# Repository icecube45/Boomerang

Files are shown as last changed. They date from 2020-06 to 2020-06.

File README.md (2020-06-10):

# Boomerang

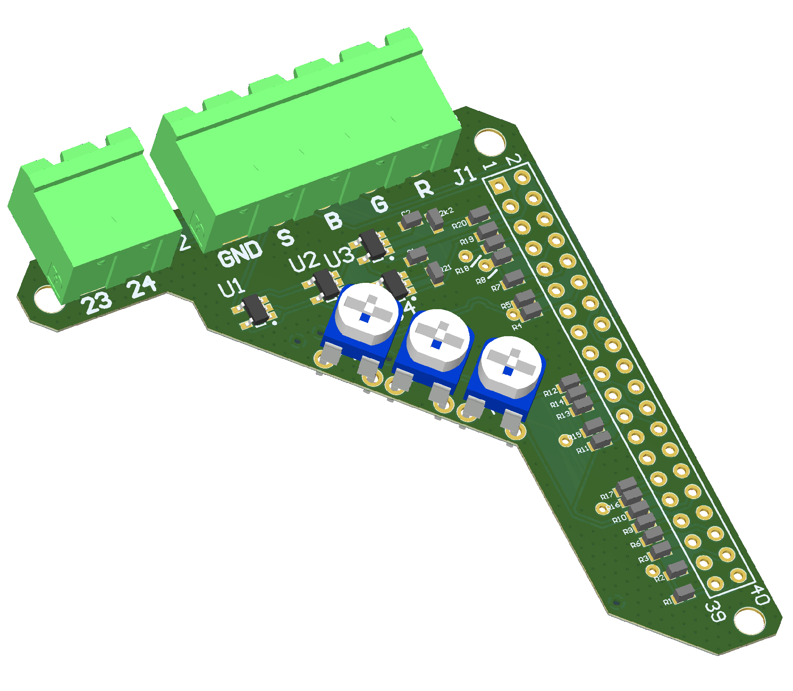
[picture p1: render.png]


## Purpose

Boomerang plugs directly into the 40 pin header of a Raspberry Pi and allows for RGBS output, rather than the usual HDMI. This board integrates a Gert VGA 666, and composite sync combiner.

Boomerang also exposes GPIO 23 and GPIO 24 to an external connector, which I'm using to communicate with a [Mausberry Car Supply](https://mausberry-circuits.myshopify.com/).

Three trimpots are installed to allow for slight color correction of the R G and B signals.

Combined with the [Screen Slaver](https://github.com/icecube45/G37ScreenSlaver), Boomerang allows for easy car computer integration into an Infiniti G37.

## Software config
The following must be added to your raspberry pi's config.txt in order to output RGBS video
```
dtoverlay=vga666
enable_dpi_lcd=1
display_default_lcd=1
dpi_group=2
dpi_mode=87
hdmi_timings=480 1 31 35 64 234 1 12 10 10 0 0 0 60 0 9600000 1
```

## Gotchas

* The effective resolution with the Boomerang and supplied config is 480x234. Not great, but actually looks ok on the Infiniti G37 display. If you find a config that allows for a 'higher' resolution, please submit a pull request!

#### Changelog:

* 6/9/2020: Initial Release

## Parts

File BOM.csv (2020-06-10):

Comment | Description | Designator | Footprint | Quantity
Res3 | Resistor | 2k2 | 1608[0603] | 1
22uF | Capacitor | C1, C2 | 1608[0603] | 2
CONN SOCKET 20x2 | Pi 40 pin 2.54mm connector | J1 |  | 1
GPIO Connector | Phoenix Connect | J2 | 1757242 | 1
Video Output | Phoenix Connect | J3 | 1757271 | 1
499 1% |  | R1, R7, R13 | 1608[0603] | 3
1K |  | R2, R8, R14 | 1608[0603] | 3
2K |  | R3, R9, R15 | 1608[0603] | 3
4K |  | R4, R10, R16 | 1608[0603] | 3
8K |  | R5, R11, R17 | 1608[0603] | 3
16K |  | R6, R12, R18 | 1608[0603] | 3
120 |  | R19, R20 | 1608[0603] | 2
2k2 | Resistor | R21 | 1608[0603] | 1
TrimPot | 15k | T1, T2, T3 | 3Wire_Trimpot | 3
SN74LVC1G86DBVR | Single 2-Input Exclusive-OR Gate, DBV0005A, LARGE T&R | U1, U2, U3, U4 | DBV0005A_N | 4

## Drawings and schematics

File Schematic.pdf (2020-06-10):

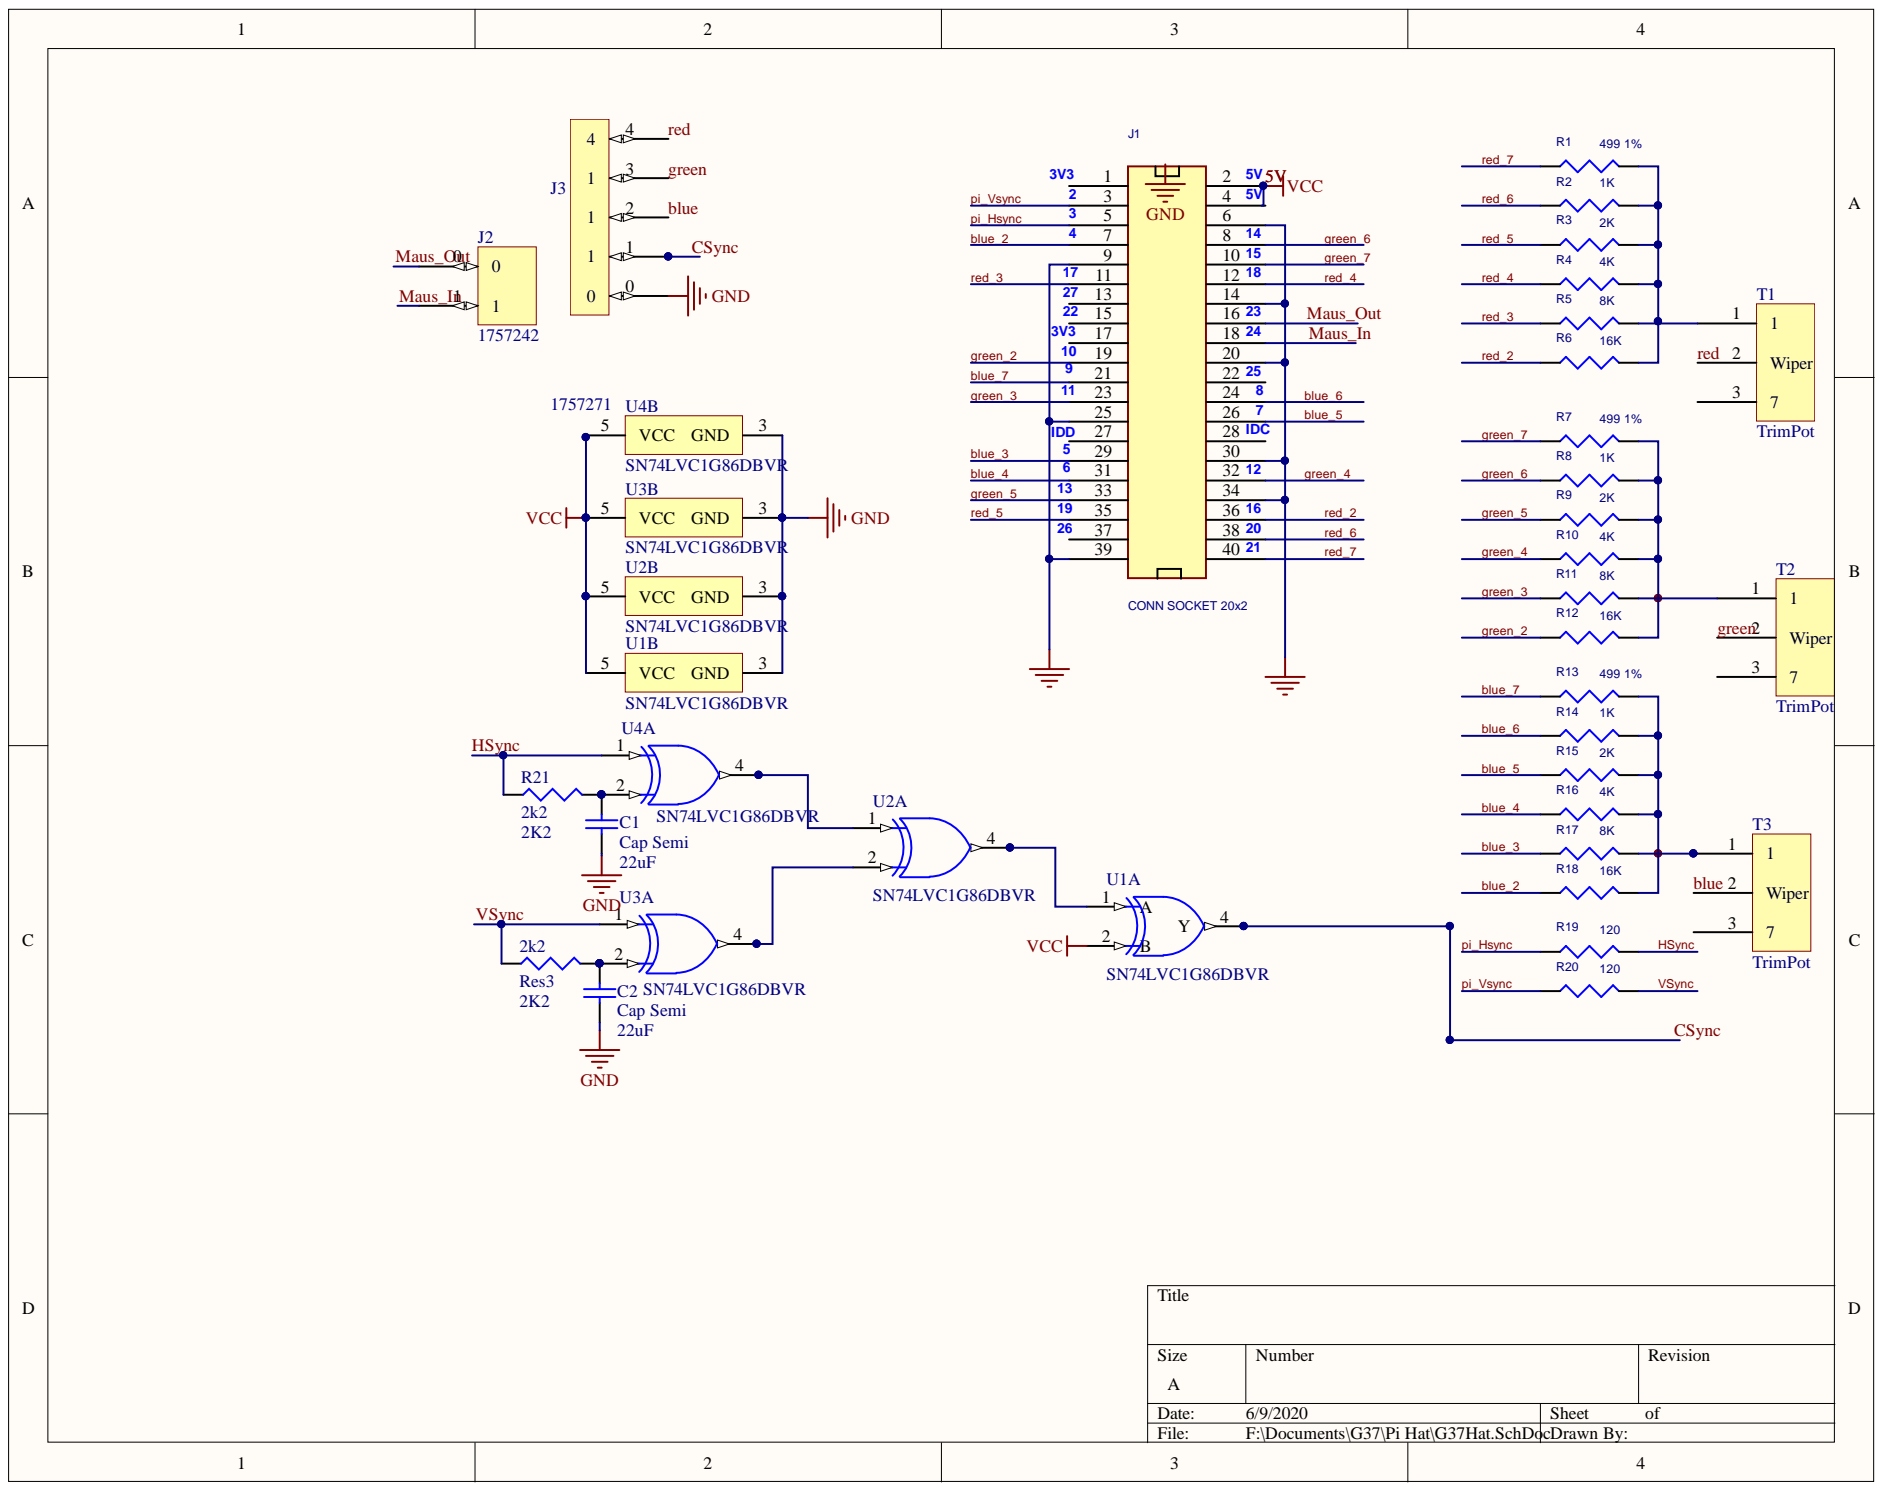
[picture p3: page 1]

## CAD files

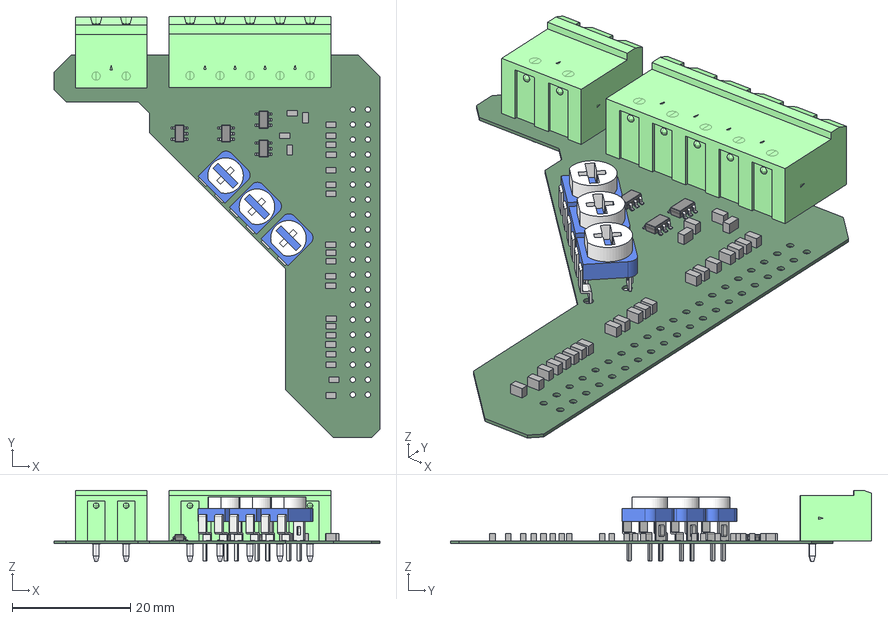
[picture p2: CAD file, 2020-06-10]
Boomerang.step
55.1 x 71.2 x 12.1 mm
Pot_-_RES_VAR1 x 3
mstba_2.5-2-g-5.08
Extruded x 24
mstba_2.5-5-g-5.08
BODY_MF05A x 4
LEAD_MF05F x 20
